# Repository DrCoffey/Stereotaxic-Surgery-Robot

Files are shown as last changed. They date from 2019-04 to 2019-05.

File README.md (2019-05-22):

# Stereotaxic Surgery Robot

This is an adaptation of the open-source robot stereotaxic instrument originally described by [Coffey et al., 2013.](https://www.jove.com/video/51006/building-an-open-source-robotic-stereotaxic-instrument)

By using stepper motors and 3D printed couplers, we can upgrade an existing stereotaxic instrument to a highly precise robot instrument for approximately $350.

This repository contains the coupler and [assembly instructions](Kopf%20Ultra%20Precise%20962/Constructing%20the%20Robot.md) to convert a Kopf Ultra Precise 962.

The robot is controlled by g-code sent to a CNC controller through Mach3.  
[Mach 3 setup instructions](Mach3%20Setup.md)

##### For easy g-code generation, see this surgical [G-Code Generator.](https://github.com/MxMarx/G-Code-Generator)

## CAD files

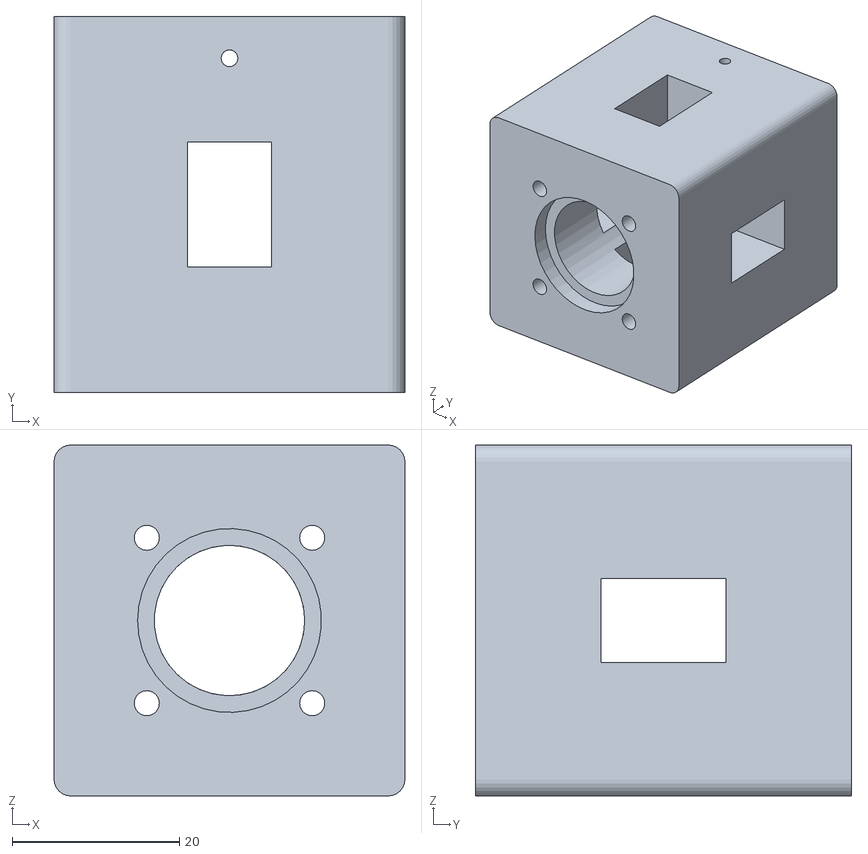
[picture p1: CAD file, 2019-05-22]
Standard Kopf/Motor Coupler ML DV.stl
42.0 x 45.0 x 42.0

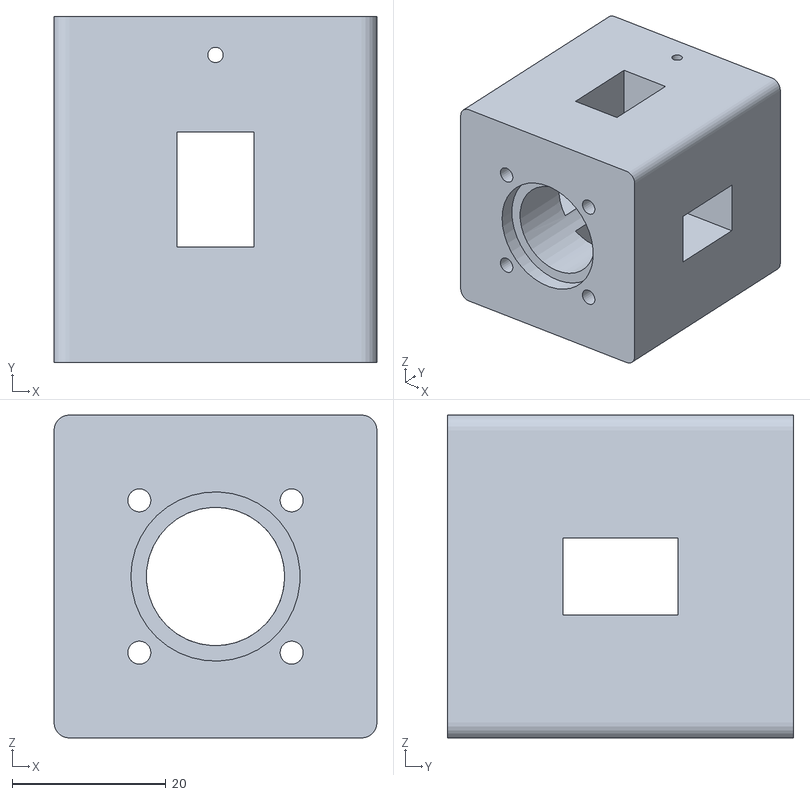
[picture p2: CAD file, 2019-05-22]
Standard Kopf/Motor Couple AP.stl
42.0 x 45.0 x 42.0

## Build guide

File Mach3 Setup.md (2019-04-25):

# Mach3 Setup
## Windows 7 Notes
[Mach3 will crash windows 7 after certain updates](https://support.machmotion.com/books/knowledge-base/page/mach3-shutting-down-pc-on-launch)

To fix this, launch cmd.exe as administrator and run the following lines:

    reg add "HKEY_LOCAL_MACHINE\SYSTEM\CurrentControlSet\Control\Session Manager\Memory Management" /v FeatureSettingsOverride /t REG_DWORD /d 3 /f

    reg add "HKEY_LOCAL_MACHINE\SYSTEM\CurrentControlSet\Control\Session Manager\Memory Management" /v FeatureSettingsOverrideMask /t REG_DWORD /d 3 /f

## Mach3 Ports and Pins settings for TB6600HG driver

##### Motor Outputs:
Signal |Step Pin# | Dir Pin#
-------|----------|---------
X Axis | 2        | 3
Y Axis | 4        | 5
Z Axis | 6        | 7

##### Output Signals
Signal    | Enabled | Pin Number | Active Low
----------|---------|------------|-----------
Enable1   | 1       | 1          | 0
Enable2   | 1       | 1          | 0
Enable3   | 1       | 1          | 0
Output #1 | 1       | 14         | 0

## Motor Tunings:

Motor tuning will depend on the micro-step mode, as well as the stereotaxic instrument's lead screw.

"Steps per" defines the steps per unit. To make g-codes easy to read and create, 1 unit should equal one millimeter.

"Steps per" Should equal ```micro-steps * steps/rotation * rotations/mm```

For the Kopf Ultra Precise 962 with 1 rotation/mm, with 16 micro-steps and 200 step/rotation motors, this value should be 3200.

Velocity should be approximately 125 units/mm, and acceleration should be 75 units/sec/sec.

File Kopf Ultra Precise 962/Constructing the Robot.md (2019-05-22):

# Constructing the Robot

## Parts list
| Component | Quantity | Link |
|---|---|---|
| 5mm to 5mm Flexible Shaft Couplings | 3 | https://www.amazon.com/dp/B01HBV4KCE |
| NEMA 17 Stepper motors, 40N.cm torque | 3 | https://www.amazon.com/Stepper-Motor-4-lead-Printer-Router/dp/B0716S32G4 |
| Heat Set Inserts | 6 | https://www.mcmaster.com/93365A122 |
| Set Screws | 6 | https://www.mcmaster.com/91375A106 |
| M3 Socket Head Screws | 12 | https://www.mcmaster.com/91290a123 |
| 3D Printed Coupler | 3 | https://www.shapeways.com/ (Material: Versitile Plastic, Color: Purple)  |
| TB6600HG driver | 1 | Ebay (Sellers Always Changing) |

## Assembly

* Remove the wheels from each arm of the instrument. This requires a torx bit.
  * First, unscrew the set screw on the measurement dial.
  * Beneath the dial, remove the second set screw, and pull the wheel off the arm.
* Prepare the 3D printed couplers by inserting the heat set inserts.
  * Drill holes on two adjacent sides of the coupler, at the guide holes on the side that attaches to the arm.
  * Using a soldering iron, gently press the inserts into the holes.
* Attach the 3D printed coupler to the stepper motors with the socket head screws.
* Place the 5mm shaft coupler on the arm's shaft, where the wheel attaches.
* Connect the 3D printed coupler and stepper motor to the instrument, and instert set scews.
* Tighten the shaft coupler, and reassemply the stereotaxic instrument.
